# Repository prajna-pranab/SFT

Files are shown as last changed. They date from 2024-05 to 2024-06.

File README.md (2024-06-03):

# SFT Mk 4 - FreeCAD Project
This is a [FreeCAD](https://freecad.org/) project to model the [Switched Flux Transmission](https://tomboy-pink.co.uk/SFT/) device invented by Prajna Pranab.

luxcorerender1

*SFT-Mk4 render image (using Luxcore)*

To work with the complete assembly you will need to install the following  addons via the FreeCAD Addons Manager: Assembly 4 Workbench; Fasteners Workbench; for rendering, the Render Workbench.

The model is organised as an Assembly 4 project and the assembly is contained in [asm_SFT-Mk4.FCStd](./asm_SFT-Mk4.FCStd), so open that file in FreeCAD and it will open all the other parts. Once you've opened the project file, switch to the Assembly 4 Workbench and look near the top of the tree for the Variables object. In the Variables object properties you will find a Variable called _Rotor Angle_. The moveable parts positions are all calculated from the rotor axle's angle (specified in _Rotor Angle_) and you can adjust the state of the model by changing the value of _Rotor Angle_. You can also click the Animate Assembly button and select _Rotor Angle_ as the variable to control.

For full details on what this SFT device is visit my [website](https://tomboy-pink.co.uk/SFT/)

There's plenty more to do. Some things that need checking in this model: Fitting and clearence of the holes that receive shafts and axles; I've only been working with FreeCAD for a month, so a level of inexpertise may be obvious to some skilled in the art and science of it; There is still work to do on the render setup (I'm still learning about that); I've never 3D printed anything and those who have may look at this design in horror at the lack of support or extravagant use of filament and probably other stuff I have no idea about, so I hope to find some pointers on that at our local(ish) FabLab and the design may dramatically change when I've been there. Feel free to [join the discussion][Discussion] or raise an issue if you see something that could be better.

## Update

I went to visit my local [FabLab](https://www.fablabs.io/labs/fablabaldeiasdoxisto) to discuss the project. The guy I spoke to seems to think (from a quick look at the rendered image) that the model will be easy to print but there is a week-long event at the lab this week, so it will probably be next week before there is an opportunity to sit down with them.

26 May 24 - I returned to FabLab and was given a run-through of Prusa Slicer, installed and configured it on my laptop and then laid out the printable parts in Prusa. I also emailed https://www.coleherne.co.uk/, who specialise in electrical steel laminations, to ask for advice on the suitability of electrical steel for the Tabs/Fingers. They claim to offer such expertise and have a department for prototyping laminations using a laser cutter. Hopefully they will not be put off responding because it "looks like a free energy device."

2 June 24 - Didn't hear back from Coleherne Ltd re laminations so have emailed three other lamination companies. Everything is laid out for printing and we're off to FabLab tomorrow to do that. I have started a new branch "capnut" because it was not easy to source inserts and grubscrews locally so I have refactored things to use captive nuts rather than inserts. That involved resizing various hubs and modifying/moving other parts to accommodate the nuts.

## Acknowledgements

A big shout out to Robert Murray-Smith, whose video about the Wesley Gary magnetic motor inspired this device. The wonderful renders could not have been done without the dedication and prompt updating of the FreeCAD Render Workbench by @howetuft to address issues I was having.

## Feedback and involvement

I've set up `Discussions` as a space to discuss this project.

Please be friendly and constructive. 

Here's the [Discussion][Discussion].

To follow any activity in the repository, switch on the `Watch` functionality. If you find the project interesting, please star the repository. Starring a repository also shows appreciation to the repository maintainer for their work. You can star repositories and topics to keep track of projects you find interesting and discover related content in your news feed. Check out [Saving repositories with stars](https://docs.github.com/en/get-started/exploring-projects-on-github/saving-repositories-with-stars) to get more.

[Discussion]: https://github.com/prajna-pranab/SFT/discussions

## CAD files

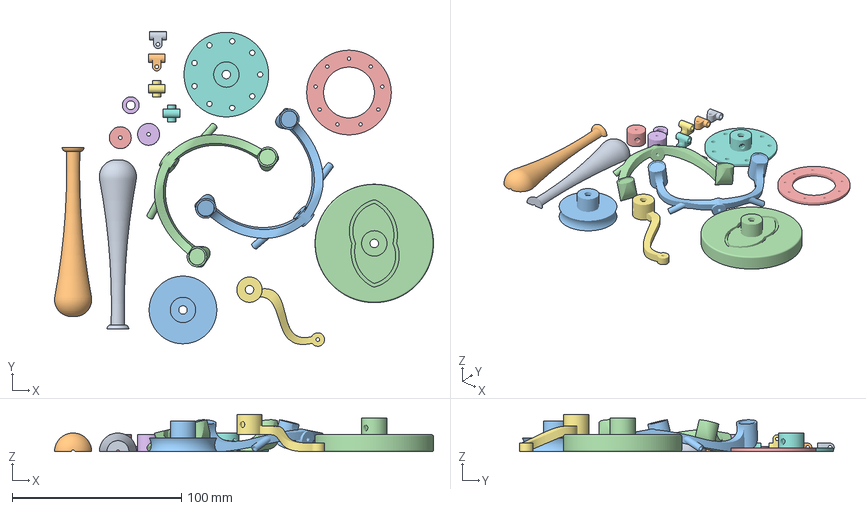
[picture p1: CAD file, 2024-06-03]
prusa/asm_SFT-Mk4-SFT print1.3mf
224.0 x 186.0 x 22.0 mm
asm_SFT-Mk4-SFTSlider Block (front).stl
asm_SFT-Mk4-SFTRocker (front).stl
asm_SFT-Mk4-SFTRotor Clamp Ring.stl
asm_SFT-Mk4-SFTRotor Bush.stl
asm_SFT-Mk4-SFTPin Block.stl
asm_SFT-Mk4-SFTHandle.stl_3 x 2
asm_SFT-Mk4-SFTPulley.stl
asm_SFT-Mk4-SFTFlywheel.stl
asm_SFT-Mk4-SFTRocker Bush.stl
asm_SFT-Mk4-SFTHandle.stl_1
asm_SFT-Mk4-SFTRotor.stl_2

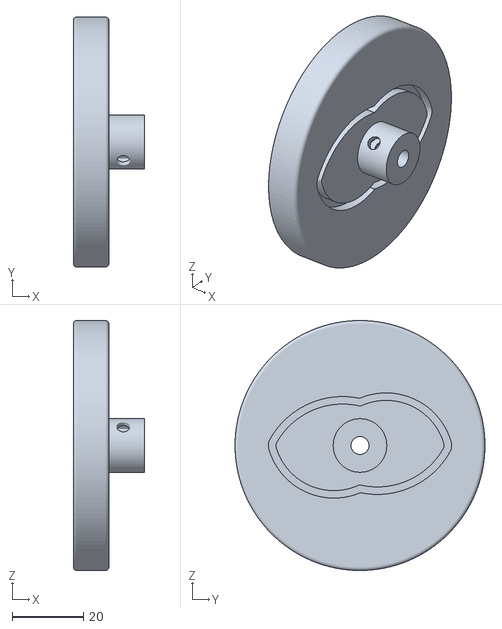
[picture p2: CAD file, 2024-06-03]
STL/asm_SFT-Mk4-SFTFlywheel.stl
20.0 x 70.0 x 70.0

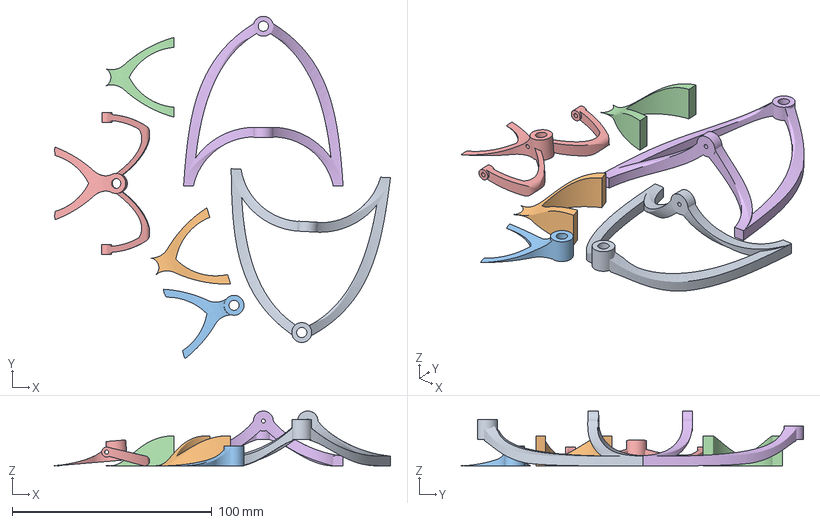
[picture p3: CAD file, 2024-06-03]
prusa/asm_SFT-Mk4-SFT print2.3mf
168.4 x 171.6 x 27.5 mm
Base-SFTRoRo Mount.stl_2
Base-SFTFlywheel Stand (left).stl x 2
Base-SFTFlywheel Stand (right).stl x 2
asm_SFT-Mk4-SFTBase new.stl_8

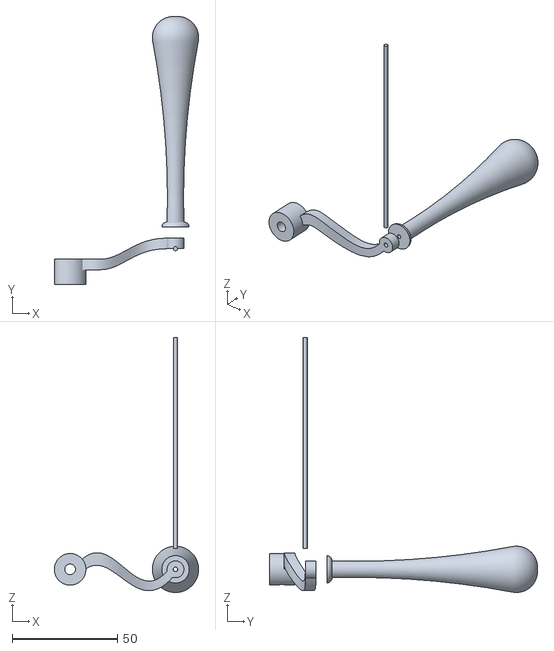
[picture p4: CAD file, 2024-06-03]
STL/asm_SFT-Mk4-SFTHandle.stl
68.5 x 127.2 x 121.0

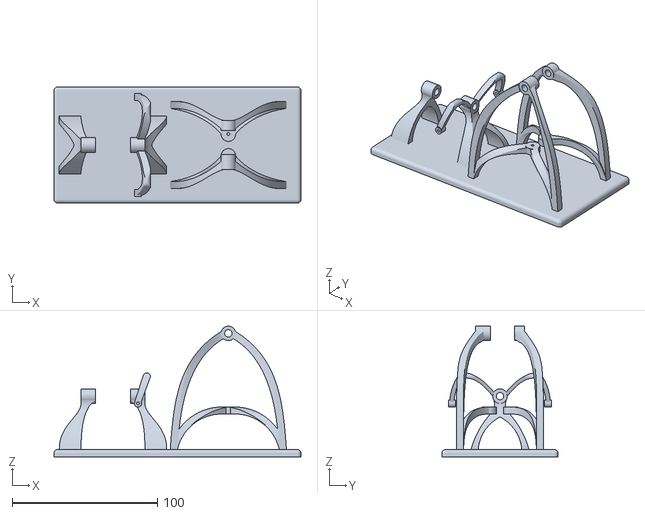
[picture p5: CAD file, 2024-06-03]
STL/asm_SFT-Mk4-SFTBase new.stl
170.0 x 80.0 x 90.0

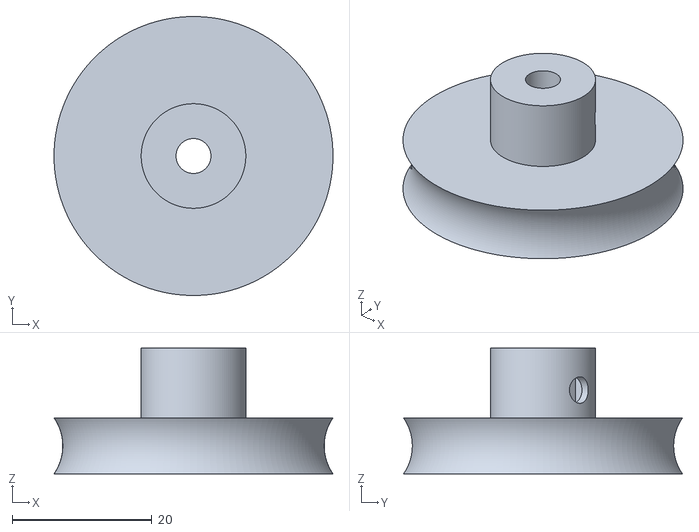
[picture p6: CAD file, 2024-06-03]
STL/asm_SFT-Mk4-SFTPulley.stl
40.0 x 40.0 x 18.0

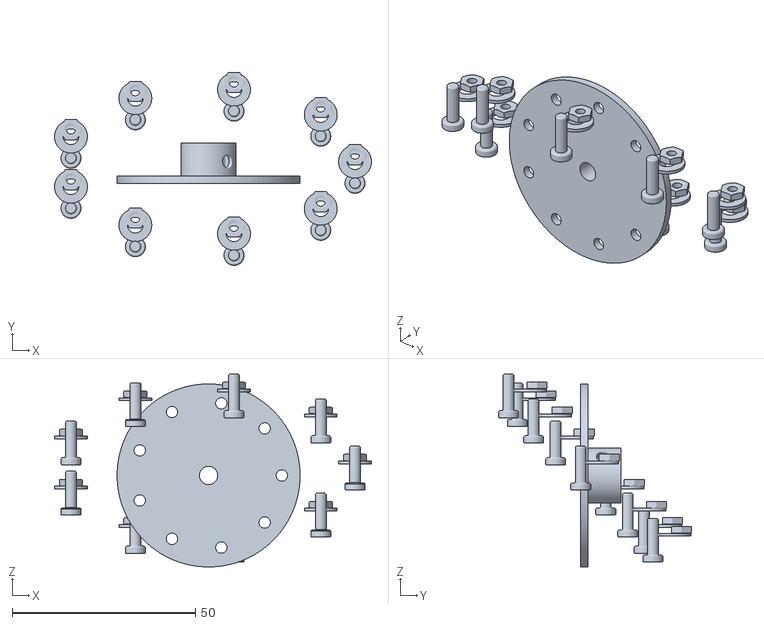
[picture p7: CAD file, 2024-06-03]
STL/asm_SFT-Mk4-SFTRotor.stl
86.6 x 52.7 x 52.7

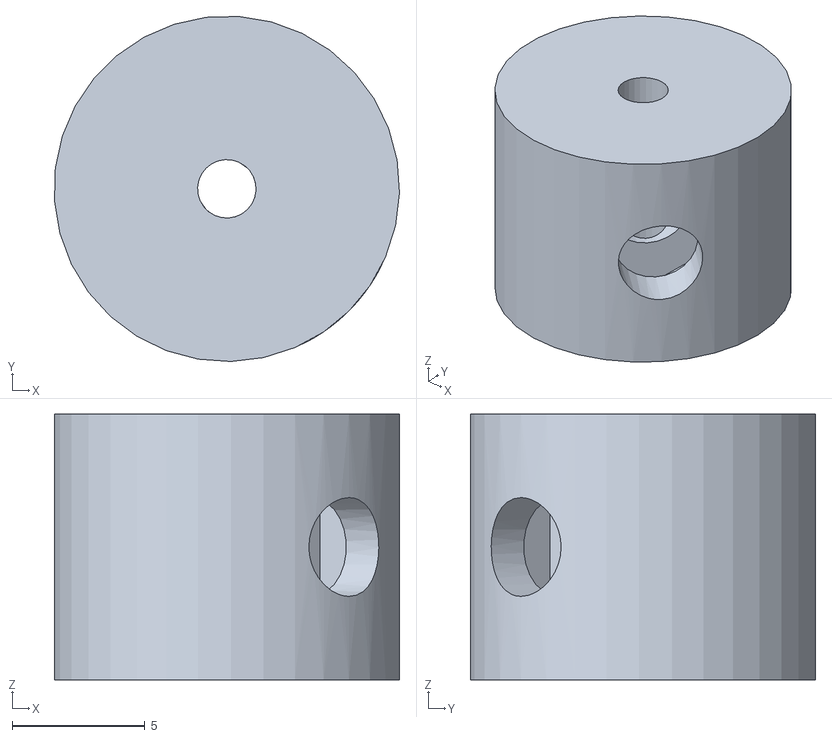
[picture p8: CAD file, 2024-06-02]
STL/asm_SFT-Mk4-SFTRocker Bush.stl
13.0 x 13.0 x 10.0

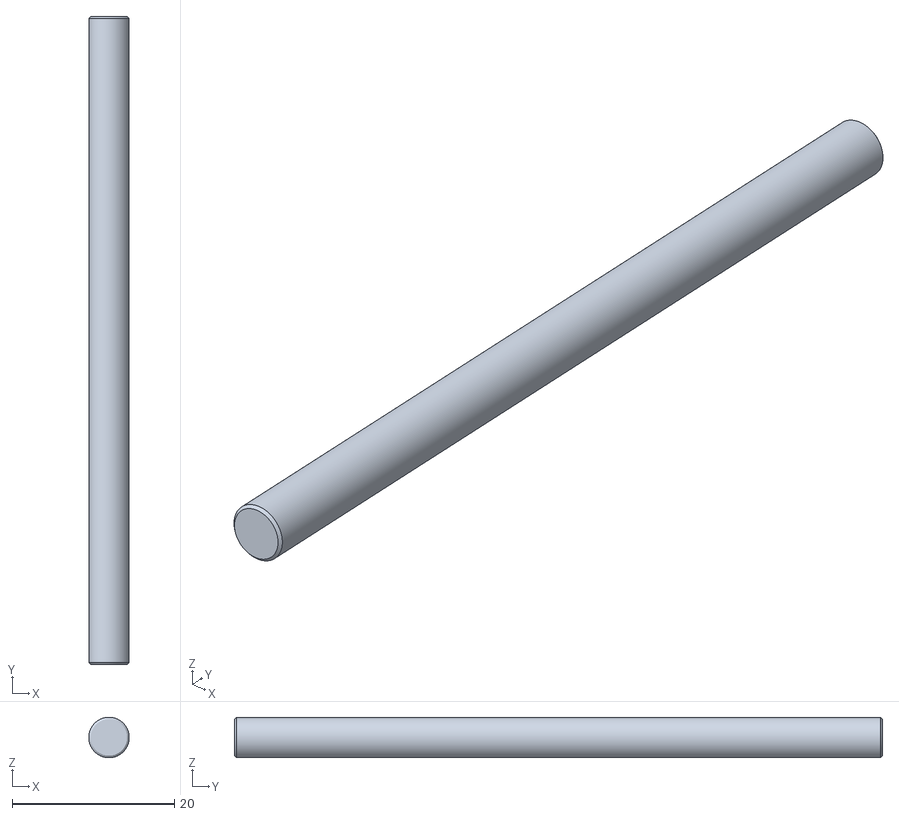
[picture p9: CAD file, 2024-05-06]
STL/asm_SFT-Mk4-SFTRotor Axle.stl
5.00 x 80.0 x 5.00

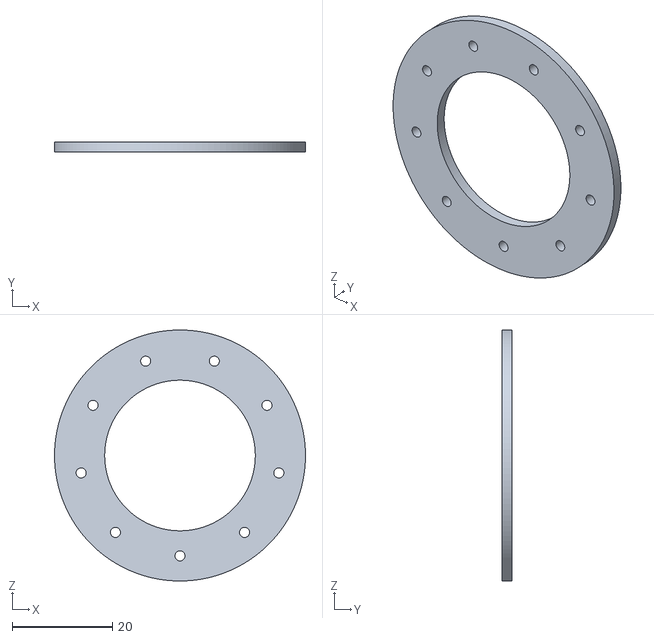
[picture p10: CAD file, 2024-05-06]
STL/asm_SFT-Mk4-SFTRotor Clamp Ring.stl
50.0 x 2.00 x 50.0

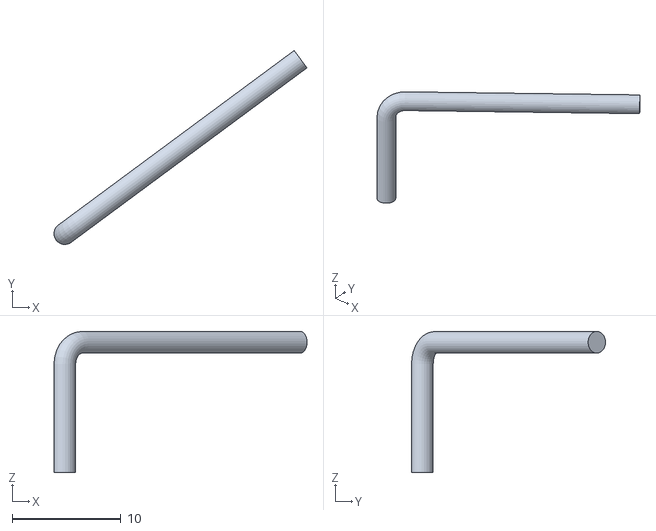
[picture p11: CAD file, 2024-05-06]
STL/asm_SFT-Mk4-SFTRocker Leg.stl
23.3 x 17.9 x 13.0

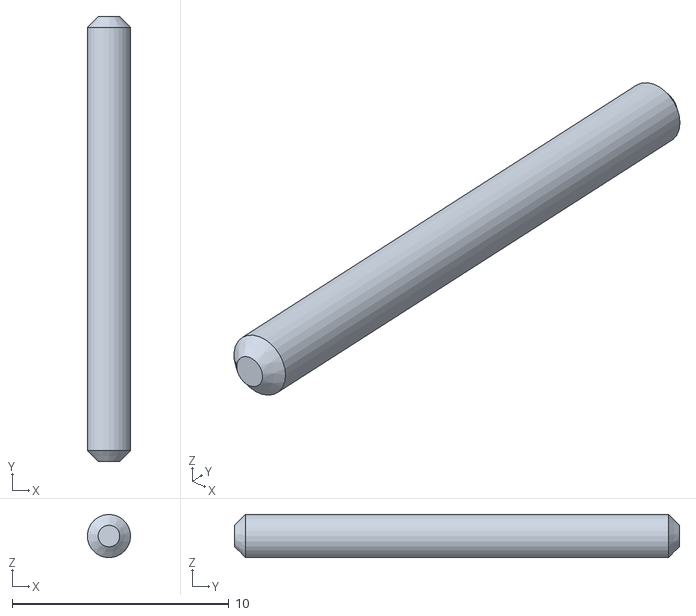
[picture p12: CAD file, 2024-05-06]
STL/asm_SFT-Mk4-SFTRocker Axle.stl
2.00 x 20.5 x 2.00

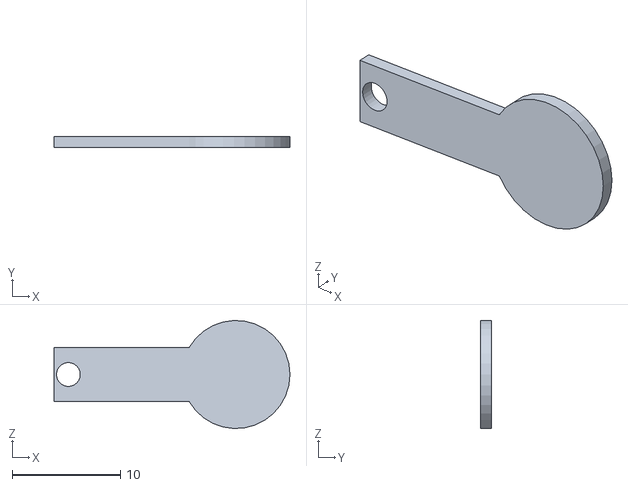
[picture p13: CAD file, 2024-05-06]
STL/asm_SFT-Mk4-SFTFing.stl
21.8 x 1.00 x 9.99

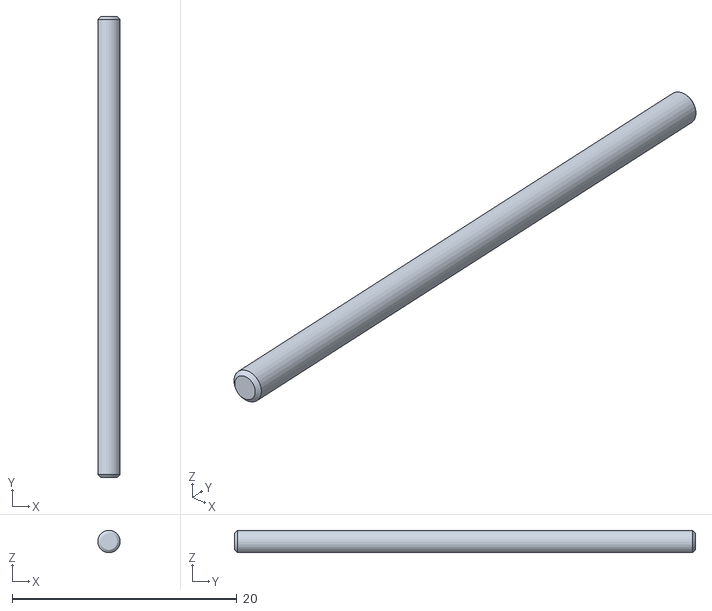
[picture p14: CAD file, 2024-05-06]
STL/asm_SFT-Mk4-SFTSlider Bar.stl
2.00 x 41.0 x 2.00

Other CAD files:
STL/asm_SFT-Mk4-SFTRocker.stl
STL/asm_SFT-Mk4-SFTFlywheel Axle.stl
STL/asm_SFT-Mk4-SFTSlider Block.stl
STL/asm_SFT-Mk4-SFTPin Bar.stl
Base.FCStd
Fing.FCStd
Flywheel Axle.FCStd
Flywheel Weight.FCStd
Flywheel.FCStd
Handle.FCStd
M2 Bush.FCStd
Magnet.FCStd
Pin Bar.FCStd
Pin Block.FCStd
Pin Rod.FCStd
Pulley 2.FCStd
Pully.FCStd
Rocker Axle.FCStd
Rocker Leg.FCStd
Rocker.FCStd
Rotor Axle.FCStd
Rotor Clamp Ring.FCStd
Rotor.FCStd
STL/Base-Base (Stands Unfused).stl
STL/asm_SFT-Mk4-SFTFlywheel Weight.stl
Slider Bar.FCStd
Slider Block.FCStd
Slider Rod.FCStd
asm_SFT-Mk4.FCStd
prusa/Captive Nut Test.3mf
shaft.FCStd

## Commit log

2024-04-28 Add files via upload
    Added the .FCStd files
    [Base.FCStd, Fing.FCStd, Flywheel Axle.FCStd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]
2024-04-28 Fix 'Part moves to origin in render'
    [Fing.FCStd, Flywheel Axle.FCStd, Flywheel.FCStd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]
2024-04-29 Update README.md
    Added info on opening the project in FreeCAD and changing the rotor angle (and everything connected with that)
2024-04-30 Error applying MaterialX
    Trying to apply GPUOpen TH_Wood_Table to the Handle Grip resulted in an error.
2024-04-30 Modified a few materials
    Changed display materials (but not render materials, which are still giving out of scope errors).
    [Pully.FCStd, Rotor Clamp Ring.FCStd]
2024-04-30 More rendering mods
    Corrected some Out Of Scope errors when assigning materials by dragging the affected parts to the assembly root and then back to their groups.
2024-05-01 Render Updates
    Added HDRI Image light. Appleseed and Povray render setups.
    [Handle.FCStd, Rotor Axle.FCStd, Rotor.FCStd]
2024-05-02 Changed some colours
    Changed colours of the pin blocks and slider blocks as well as the handle grip before doing a new animation.
    [Handle.FCStd, Pin Block.FCStd, Slider Block.FCStd]
2024-05-05 Render update
    Added some more render engines. This commit to present the Luxcore setup to @howetuft for debugging.
    [Fing.FCStd, Flywheel Axle.FCStd, Flywheel.FCStd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]
2024-05-06 Added STL files
    STL files for everything except fixings. Some of the objects, like the handle, include the individual parts (Arm, Grip, Shaft). The base will have to be re-exported for the next commit because some parts of it are missing or detached in the STL file.
    [asm_SFT-Mk4-SFTBase.stl, asm_SFT-Mk4-SFTFing1.stl, asm_SFT-Mk4-SFTFlywheel Axle.stl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]
2024-05-06 Updated Base
    Fused the hubs to the stands but the mirrored stands are not showing.
    [Base-Base (Stands Unfused).stl, Base.FCStd]
2024-05-06 Updated Base
    Fused the parts used in the Base and exported a new Base STL file.
    Removed a few superfluous files that are no longer needed.
    [Base-Base (Stands Unfused).stl, Base.FCStd, M5 Bush.FCStd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]
2024-05-06 Corrected Animation
    Reassigned the rotation axis for the Rotor Axle, which got messed up when rearranging things for the STL exports.
2024-05-26 Test large file upload
    Added Prusa slicer files but they failed to upload (probbably too big), so added Git LFA. This commit to test LFA upload.
    [asm_SFT-Mk4-SFT print1.3mf, asm_SFT-Mk4-SFT print2.3mf]
2024-05-26 Added printer layouts
    Updated some parts for better 3D printing and updated STL files, added Prusa layouts. Some parts (pulley and flywheel stands) are split using Prusa's cut tool for better support.
    [Base-Base (Stands Unfused).stl, Base.FCStd, Flywheel.FCStd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]
2024-05-26 Updated readme
    Added info about progress on printing and sourcing electrical steel.
2024-05-27 Updates for printing
    Redesigned the pulley for better printing, changed print layout for faster printing and renamed some of the STL files.
    [Fing.FCStd, Flywheel Axle.FCStd, Flywheel.FCStd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]
2024-06-02 New Branch for Captive Nuts
    This branch uses captive nuts rather than IUTHeatInserts and grubscrews, so all the hubs have had to be resized to accommodate the nuts, with knock-on effects on the positioning of other parts.
    [Base.FCStd, Flywheel Axle.FCStd, Flywheel.FCStd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]
2024-06-03 Correct nut pocket dims
    Increased the size of the captive nut pockets having done a test print. New layouts with correct pocket sizes. Deleted a couple of redundant files.
    [Captive Nut Test.3mf, Flywheel.FCStd, Handle.FCStd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]
